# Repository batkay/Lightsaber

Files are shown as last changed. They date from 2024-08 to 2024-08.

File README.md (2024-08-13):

# Lightsaber
Repository for custom lightsaber PCB and firmware
## Overview
The firmware folder contains the STMCubeIDE project used to program the STM32F446RE, and the LightsaberDesign folder contains the KiCad project for the PCB used. The Outputs folder contains the outputs from KiCad that was sent to JLCPCB for assembly. The project has been changed since Outputs was last updated, so the folder is not up to date. SpiceSimulations contains the LTSpice simulations used when designing the PCB.
## Obtaining audio
The audio file was obtained by taking a wav file from online, importing it into Audacity, then exporting it as a monochannel 8-bit audio file at 8000Hz. This then allowed the file to be played with interrupts instead of using a DMA.
## Known Issues
When playing audio from the speaker, the noise is extremely noisy. The source of this noise is not currently known, but it is likely due to a hardware issue, as the original noise file can very faintly be heard in the noise.

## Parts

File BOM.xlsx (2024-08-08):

0805 2k resistor | ERJ-6ENF2001V | https://www.digikey.com/en/products/detail/panasonic-electronic-components/ERJ-6ENF2001V/111341 | 1
Load Switch | AP22814AW5-7 | https://www.digikey.com/en/products/detail/diodes-incorporated/AP22814AW5-7/6602438 | 1
PMOS | BSS83PH6327XTSA1 | https://www.digikey.com/en/products/detail/infineon-technologies/BSS83PH6327XTSA1/2783473 | 1
0.1uF 0805 capacitor | CC0805KRX7R9BB104 | https://www.digikey.com/en/products/detail/yageo/CC0805KRX7R9BB104/302874 | 4
1uF 0805 capacitor | CC0805KKX7R7BB105 | https://www.digikey.com/en/products/detail/yageo/CC0805KKX7R7BB105/2103103 | 7
smd jst | B3B-PH-SM4-TB | https://www.digikey.com/en/products/detail/jst-sales-america-inc/B3B-PH-SM4-TB/926642 | 1
Vertical jst | B3B-XH-A | https://www.digikey.com/en/products/detail/jst-sales-america-inc/B3B-XH-A/1651046 | 1?
nmos | 2N7002-TP | https://www.digikey.com/en/products/detail/micro-commercial-co/2N7002-TP/1959296 | 1
Molex header | 530470210 | https://www.digikey.com/en/products/detail/molex/0530470210/242853 | 2
Diode | BAS16,215 | https://www.digikey.com/en/products/detail/nexperia-usa-inc/BAS16-215/763200 | 1
Programming header | FTSH-105-01-F-DV-K-P-TR | https://www.digikey.com/en/products/detail/samtec-inc/FTSH-105-01-F-DV-K-P-TR/2649977 | 1
Crystal | ABLS-16.000MHZ-B4-T | https://www.digikey.com/en/products/detail/abracon-llc/ABLS-16-000MHZ-B4-T/2184169 | 1
Ferrite Bead | BLM18KG121TN1D | https://www.digikey.com/en/products/detail/murata-electronics/BLM18KG121TN1D/1982762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 | 1
audio amp | TPA301DR | https://www.digikey.com/en/products/detail/texas-instruments/TPA301DR/374565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 | 1
stm32 | STM32F446RET6 | https://www.digikey.com/en/products/detail/stmicroelectronics/STM32F446RET6/5175962 | 1
shocktty diode | BAS3010A03WE6327HTSA1 | https://www.digikey.com/en/products/detail/infineon-technologies/BAS3010A03WE6327HTSA1/1280885 | 1
0805 inductor | LQM21PN4R7MGRD | https://www.digikey.com/en/products/detail/murata-electronics/LQM21PN4R7MGRD/4359176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 | 1
0805 10k resistor | RC0805FR-0710KL | https://www.digikey.com/en/products/detail/yageo/RC0805FR-0710KL/727535 | 7
0805 12k resistor | RMCF0805JT12K0 | https://www.digikey.com/en/products/detail/stackpole-electronics-inc/RMCF0805JT12K0/1711867 | 1
0805 6.19k | RC0805FR-076K19L | https://www.digikey.com/en/products/detail/yageo/RC0805FR-076K19L/728052 | 1
0805 50k | MCU08050D5002BP100 | https://www.digikey.com/en/products/detail/vishay-beyschlag-draloric-bc-components/MCU08050D5002BP100/8125783 | 1
Programming header | 15910100 | https://www.digikey.com/en/products/detail/molex/0015910100/614775 | 1

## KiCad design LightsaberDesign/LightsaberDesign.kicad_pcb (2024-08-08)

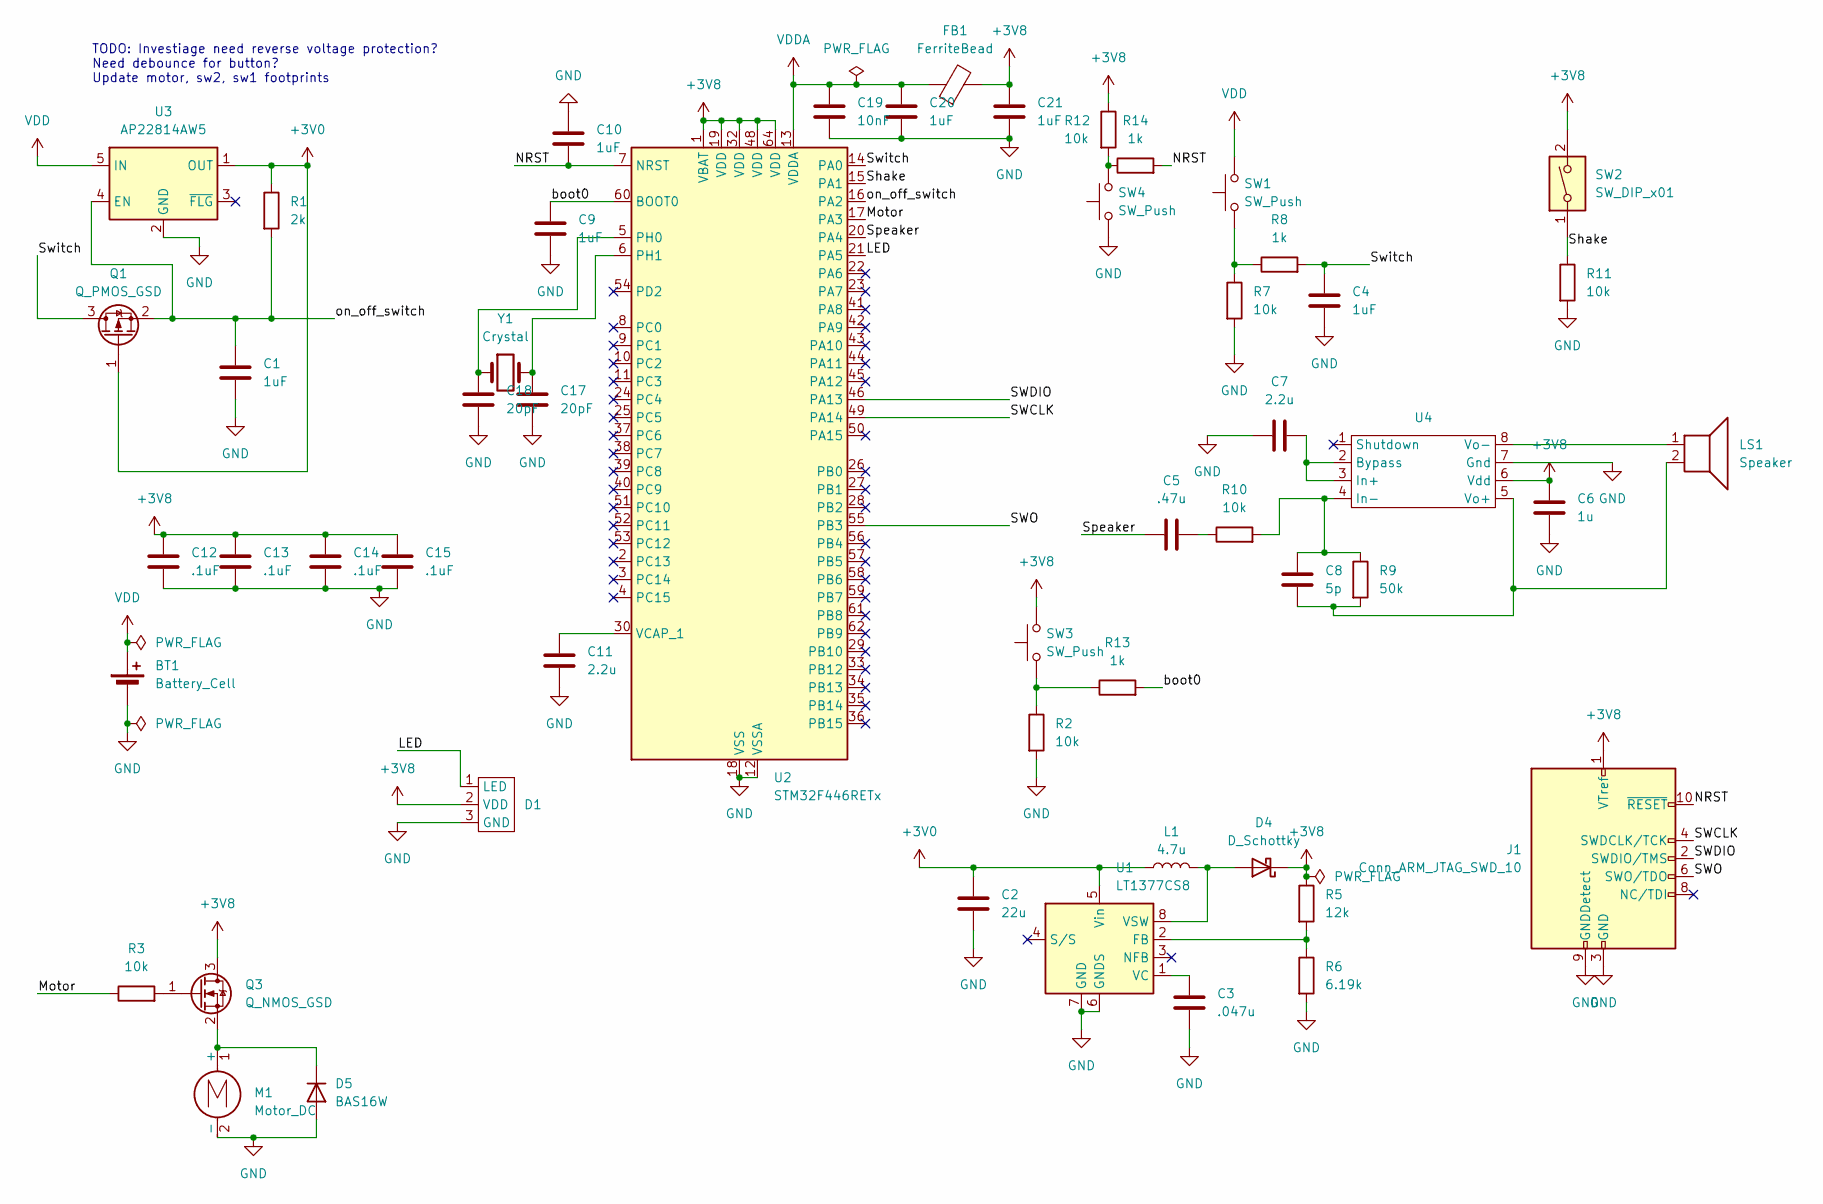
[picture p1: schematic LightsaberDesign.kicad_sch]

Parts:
BT1: Battery_Cell; JST_PH_B2B-PH-K_1x02_P2.00mm_Vertical
C1, C4, C9, C10, C20, C21: 1uF; C_0805_2012Metric_Pad1.18x1.45mm_HandSolder
C2: 22u; C_0805_2012Metric_Pad1.18x1.45mm_HandSolder
C3: .047u; C_0805_2012Metric_Pad1.18x1.45mm_HandSolder
C5: .47u; C_0805_2012Metric_Pad1.18x1.45mm_HandSolder
C6: 1u; C_0805_2012Metric_Pad1.18x1.45mm_HandSolder
C7, C11: 2.2u; C_0805_2012Metric_Pad1.18x1.45mm_HandSolder
C8: 5p; C_0805_2012Metric_Pad1.18x1.45mm_HandSolder
C12, C13, C14, C15: .1uF; C_0805_2012Metric_Pad1.18x1.45mm_HandSolder
C17, C18: 20pF; C_0805_2012Metric_Pad1.18x1.45mm_HandSolder
C19: 10nF; C_0805_2012Metric_Pad1.18x1.45mm_HandSolder
D1: JST_PH_B3B-PH-K_1x03_P2.00mm_Vertical
D4: D_Schottky; D_SOD-323_HandSoldering
D5: BAS16W; SOT-323_SC-70
FB1: FerriteBead; C_0805_2012Metric_Pad1.18x1.45mm_HandSolder
J1: Conn_ARM_JTAG_SWD_10; Samtec_HLE-105-02-xxx-DV_2x05_P2.54mm_Horizontal
L1: 4.7u; L_0805_2012Metric_Pad1.15x1.40mm_HandSolder
LS1: Speaker; Molex_PicoBlade_53047-0210_1x02_P1.25mm_Vertical
M1: Motor_DC; Molex_PicoBlade_53047-0210_1x02_P1.25mm_Vertical
Q1: Q_PMOS_GSD; TSOT-23_HandSoldering
Q3: Q_NMOS_GSD; SOT-23-3
R1: 2k; R_0805_2012Metric_Pad1.20x1.40mm_HandSolder
R2, R3, R7, R10, R11, R12: 10k; R_0805_2012Metric_Pad1.20x1.40mm_HandSolder
R5: 12k; R_0805_2012Metric_Pad1.20x1.40mm_HandSolder
R6: 6.19k; R_0805_2012Metric_Pad1.20x1.40mm_HandSolder
R8, R13, R14: 1k; R_0805_2012Metric_Pad1.20x1.40mm_HandSolder
R9: 50k; R_0805_2012Metric_Pad1.20x1.40mm_HandSolder
SW1: SW_Push; PinHeader_1x02_P2.54mm_Vertical
SW2: SW_DIP_x01; CP_Radial_D4.0mm_P1.50mm
SW3, SW4: SW_Push; SW_PUSH_6mm
U1: LT1377CS8; SOIC-8_3.9x4.9mm_P1.27mm
U2: STM32F446RETx; LQFP-64_10x10mm_P0.5mm
U3: AP22814AW5; SOT-23-5
U4: SOIC-8_3.9x4.9mm_P1.27mm
Y1: Crystal; Crystal_SMD_HC49-SD

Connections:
+3V0: C2.1, L1.1, Q1.1 (G), R1.1, U1.5 (Vin), U3.1 (OUT)
+3V8: C6.1, C12.1, C13.1, C14.1, C15.1, C21.1, D1.2 (VDD), D4.1 (K), FB1.2, J1.1 (VTref), Q3.3 (D), R5.1, R12.1, SW2.2, SW3.2, U2.1 (VBAT), U2.19 (VDD), U2.32 (VDD), U2.48 (VDD), U2.64 (VDD), U4.6 (Vdd)
/LED: D1.1 (LED), U2.21 (PA5)
/Motor: R3.1, U2.17 (PA3)
/NRST: C10.2, J1.10 (~RESET), R14.2, U2.7 (NRST)
/SWCLK: J1.4 (SWDCLK/TCK), U2.49 (PA14)
/SWDIO: J1.2 (SWDIO/TMS), U2.46 (PA13)
/SWO: J1.6 (SWO/TDO), U2.55 (PB3)
/Shake: R11.1, SW2.1, U2.15 (PA1)
/Speaker: C5.1, U2.20 (PA4)
/Switch: C4.1, Q1.3 (D), R8.2, U2.14 (PA0)
/boot0: C9.1, R13.2, U2.60 (BOOT0)
/on_off_switch: C1.1, Q1.2 (S), R1.2, U2.16 (PA2), U3.4 (EN)
GND: BT1.2 (-), C1.2, C2.2, C3.2, C4.2, C6.2, C7.2, C9.2, C10.1, C11.2, C12.2, C13.2, C14.2, C15.2, C17.2, C18.2, C19.2, C20.2, C21.2, D1.3 (GND), D5.1 (A), J1.3 (GND), J1.5 (GND), J1.9 (GNDDetect), M1.2 (-), R2.2, R6.2, R7.2, R11.2, SW4.1, U1.6 (GNDS), U1.7 (GND), U2.12 (VSSA), U2.18 (VSS), U2.31 (VSS), U2.47 (VSS), U2.63 (VSS), U3.2 (GND), U4.7 (Gnd)
unnamed: C5.2, R10.1
unnamed: D4.2 (A), L1.2, U1.8 (VSW)
unnamed: D5.3 (K), M1.1 (+), Q3.2 (S)
unnamed: Q3.1 (G), R3.2
unnamed: R7.1, R8.1, SW1.1
unnamed: R12.2, R14.1, SW4.2
unnamed: R2.1, R13.1, SW3.1
unnamed: R5.2, R6.1, U1.2 (FB)
unnamed: C3.1, U1.1 (VC)
unnamed: C18.1, U2.5 (PH0), Y1.1
unnamed: C17.1, U2.6 (PH1), Y1.2
unnamed: C11.1, U2.30 (VCAP_1)
unnamed: C7.1, U4.2 (Bypass), U4.3 (In+)
unnamed: C8.2, R9.1, R10.2, U4.4 (In-)
unnamed: C8.1, LS1.2, R9.2, U4.5 (Vo+)
unnamed: LS1.1, U4.8 (Vo-)
VDD: BT1.1 (+), SW1.2, U3.5 (IN)
VDDA: C19.1, C20.1, FB1.1, U2.13 (VDDA)

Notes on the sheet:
TODO: Investiage need reverse voltage protection? Need debounce for button? Update motor, sw2, sw1 footprints

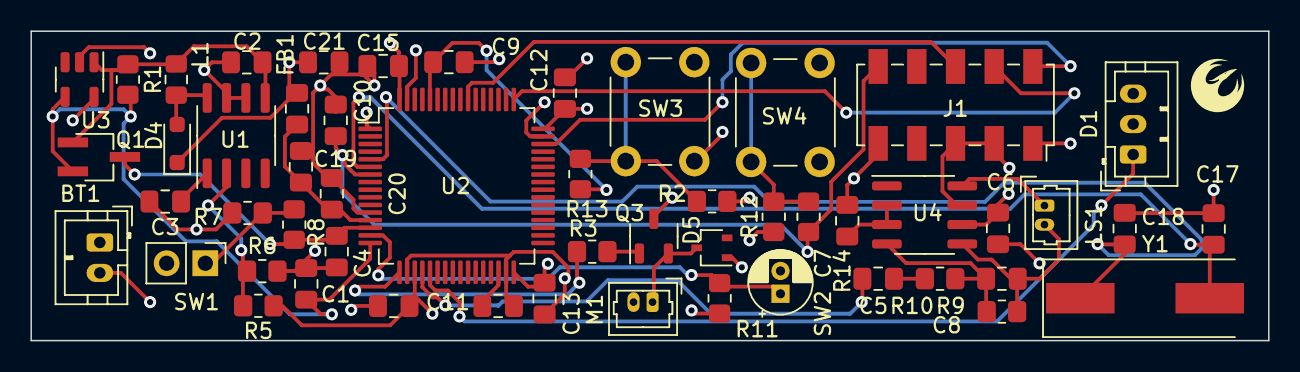
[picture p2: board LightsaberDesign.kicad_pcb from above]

Board: 4 copper layers, 81.3 x 20.3 mm, 53 parts (0 on the bottom side), 32 nets.

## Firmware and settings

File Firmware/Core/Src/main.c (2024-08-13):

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
/* Includes ------------------------------------------------------------------*/
#include "main.h"

/* USER CODE BEGIN Includes */
#include "sound.h"
/* USER CODE END Includes */

/* USER CODE BEGIN PTD */
// Datatype to store the color to be sent to neopixels. Only lower 24 bits are used
typedef union {
	struct {
		uint8_t b;
		uint8_t r;
		uint8_t g;
	} color;
	uint32_t data;
} PixelGRB_t;
// Datatype to determine state of lightsaber
enum STATE {
	STARTUP,
	LIGHT,
	OFF
};

/* USER CODE END PTD */

/* USER CODE BEGIN PD */
#define NEOPIXEL_ZERO 5 // Needs to be high for 1/4 of 20 ticks
#define NEOPIXEL_ONE 10 // high for 1/2 of 20 ticks

#define NUM_PIXELS 30

#define DMA_BUFF_SIZE (NUM_PIXELS * 24) + 1
/* USER CODE END PD */

DAC_HandleTypeDef hdac;

TIM_HandleTypeDef htim2;
TIM_HandleTypeDef htim5;
TIM_HandleTypeDef htim6;
DMA_HandleTypeDef hdma_tim2_ch1;

/* USER CODE BEGIN PV */
int soundIndex = 0;
int play = 0;
int rep = 0;
/* USER CODE END PV */

void SystemClock_Config(void);
static void MX_GPIO_Init(void);
static void MX_DMA_Init(void);
static void MX_DAC_Init(void);
static void MX_TIM2_Init(void);
static void MX_TIM6_Init(void);
static void MX_TIM5_Init(void);
/* USER CODE BEGIN 0 */
void HAL_TIM_PWM_PulseFinishedCallback(TIM_HandleTypeDef *htim)
{
  HAL_TIM_PWM_Stop_DMA(htim, TIM_CHANNEL_1);
}
void HAL_TIM_PeriodElapsedCallback(TIM_HandleTypeDef *htim) {
  // callback updates sound every 125us
	if (htim == &htim6) {
		if (play) {
			HAL_DAC_SetValue(&hdac, DAC_CHANNEL_1, DAC_ALIGN_8B_R, swing[soundIndex]);
			soundIndex++;
			if (soundIndex >= 4272) {
				soundIndex = 0;
				play = 0;
				rep = 1;
			}
		}
		else {
			if (rep) {
				HAL_DAC_SetValue(&hdac, DAC_CHANNEL_1, DAC_ALIGN_12B_R, 0);
				rep = 0;
			}

		}
	}
}
/* USER CODE END 0 */

/**
  * @brief  The application entry point.
  * @retval int
  */
int main(void)
{

  /* USER CODE BEGIN 1 */
	PixelGRB_t pixels[NUM_PIXELS];
	uint32_t dmaBuff [DMA_BUFF_SIZE];
  /* USER CODE END 1 */

  /* MCU Configuration--------------------------------------------------------*/

  /* Reset of all peripherals, Initializes the Flash interface and the Systick. */
  HAL_Init();

  /* Configure the system clock */
  SystemClock_Config();

  /* Initialize all configured peripherals */
  MX_GPIO_Init();
  MX_DMA_Init();
  MX_DAC_Init();
  MX_TIM2_Init();
  MX_TIM6_Init();
  MX_TIM5_Init();
  /* USER CODE BEGIN 2 */
  int nextLightTime = 100;
  enum STATE currentState = STARTUP;
  int prevButton = 0;
  int offTime;
  int litPixels = 0;
  HAL_DAC_Start(&hdac, DAC_CHANNEL_1);
  HAL_TIM_Base_Start_IT(&htim6);
  HAL_DAC_SetValue(&hdac, DAC_CHANNEL_1, DAC_ALIGN_12B_R, 0);
  HAL_TIM_PWM_Start(&htim5, TIM_CHANNEL_4);

  /* USER CODE END 2 */

  /* Infinite loop */
  /* USER CODE BEGIN WHILE */
  while (1)
  {
	  int currentButton = HAL_GPIO_ReadPin(GPIOA, GPIO_PIN_0);
	  int lightTime = HAL_GetTick();

	  switch(currentState) {
	  case STARTUP:
      // case for after button pressed to turn on firmware, before released
		  if (!currentButton) {
			  currentState = LIGHT;
		  }
		  play = 1;
		  litPixels = 0;
      // rumble motor
		  __HAL_TIM_SET_COMPARE(&htim5, TIM_CHANNEL_4, 900);

		  break;
	  case LIGHT:
      // normal opperation state
		  if (!currentButton && prevButton) {
			  currentState = OFF;
			  offTime = lightTime;
		  }
		  __HAL_TIM_SET_COMPARE(&htim5, TIM_CHANNEL_4, 0);

		  break;
	  case OFF:
      // turn off state
		  if (lightTime - offTime > 5000) {
        // enter sleep mode
			  HAL_GPIO_WritePin(GPIOA, GPIO_PIN_2, GPIO_PIN_RESET);
		  }
		  if (!currentButton && prevButton) {
			  currentState = LIGHT;
		  }
		  break;
	  default:
		  currentState = LIGHT;

	  }
    // Updates color packet for neopixel
	  if (lightTime >= nextLightTime) {
		  nextLightTime = lightTime + 100;
		  if (currentState != OFF) {
        // for startup sequence
			  litPixels += 5;
			  if (litPixels > NUM_PIXELS) {
				  litPixels = NUM_PIXELS;
			  }
		  }
		  else {
			  litPixels -= 5;
			  if (litPixels < 0) {
				  litPixels = 0;
			  }
		  }
		  for (int i = 0; i < NUM_PIXELS; i++) {
			  if (i <= litPixels) {
				  pixels[i].color.g = 0;
				  pixels[i].color.r = 50;
				  pixels[i].color.b = 0;
			  }
			  else {
				  pixels[i].color.g = 0;
				  pixels[i].color.r = 0;
				  pixels[i].color.b = 0;
			  }

		  }
      // Sends color data to DMA
		  for (int i = 0; i < NUM_PIXELS; i++) {
			  for (int j = 0; j < 24; j++) {
				  if (((pixels[i].data) >> (23 - j)) & 0x01) {
					  dmaBuff[i * 24 + j] = NEOPIXEL_ONE;
				  }
				  else {
					  dmaBuff[i * 24 + j] = NEOPIXEL_ZERO;
				  }
			  }
		  }
		  HAL_TIM_PWM_Start_DMA(&htim2, TIM_CHANNEL_1, dmaBuff, DMA_BUFF_SIZE);
	  }
	  prevButton = currentButton;


    /* USER CODE END WHILE */

    /* USER CODE BEGIN 3 */
  }
  /* USER CODE END 3 */
}

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


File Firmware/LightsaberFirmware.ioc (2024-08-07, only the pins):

Mcu.UserName=STM32F446RETx
PA0-WKUP.Signal=GPIO_Input
PA1.Signal=GPIO_Input
PA13.Signal=SYS_JTMS-SWDIO
PA14.Signal=SYS_JTCK-SWCLK
PA2.Signal=GPIO_Output
PA3.Signal=S_TIM5_CH4
PA4.Signal=COMP_DAC1_group
PA5.Signal=S_TIM2_CH1_ETR
PB3.Signal=SYS_JTDO-SWO
PH0-OSC_IN.Signal=RCC_OSC_IN
PH1-OSC_OUT.Signal=RCC_OSC_OUT

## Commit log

2024-06-17 Setup schematic circuit for ship mode and connectors
    [LightsaberDesign.kicad_sch]
2024-06-18 Added button debounce, made buck 3.7v
    [LightsaberDesign.kicad_sch]
2024-06-22 New speaker module
    [LightsaberDesign.kicad_sch]
2024-06-23 Layed out pcb
    [LightsaberDesign.kicad_pcb, LightsaberDesign.kicad_sch]
2024-06-29 Added crystal, ferrite bead
    [LightsaberDesign.kicad_pcb, LightsaberDesign.kicad_sch]
2024-07-02 Finished drc
    [LightsaberDesign.kicad_pcb, LightsaberDesign.kicad_sch]
2024-07-02 Updated capacitor values
    [LightsaberDesign.kicad_pcb, LightsaberDesign.kicad_sch]
2024-07-29 Simple Neopixel driver added
    [BOM.xlsx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]
2024-08-07 Added motor rumble, started to add audio
2024-08-08 Updated PCB with new header
    [BOM.xlsx, LightsaberDesign.kicad_pcb, LightsaberDesign.kicad_sch]

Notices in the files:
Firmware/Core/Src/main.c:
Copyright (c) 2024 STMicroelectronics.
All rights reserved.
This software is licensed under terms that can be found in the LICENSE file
